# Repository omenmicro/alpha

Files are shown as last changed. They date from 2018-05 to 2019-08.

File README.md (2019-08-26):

# OMEN Alpha - [[česky](README-CZ.md)]

_8bit computer, based on 8085 CPU._



Become a Patron! (https://www.patreon.com/bePatron?u=23689010)

- [Essential ICs on AliExpress](https://alitronik.com/omen-alpha-pack/)
- [Essential ICs on eBay](https://alitronik.com/omen-alpha-pack-ebay/)

[BOM - Needed parts](./BOM.md)

I write a book about old computers. Oh, sorry: I mean "vintage computers" from the 80's. My primary goal is to show how one can build an 8bit computer from scratch.

It means: how to set up a CPU, how to connect memories, how to connect peripheral chips, and why to connect...

This computer is a "demo construction": A computer, based on 8085 CPU, with 32 kB of (EEP)ROM and 32 kB of RAM, serial connection and parallel ports. All should be as simple as possible. And here is a result.

ROM
---

Use the last Monitor file - see [sw/Monitor/v4](sw/Monitor/v4)

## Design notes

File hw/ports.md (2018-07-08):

JP2
+-----+-----+-----+-----+-----+
| GND | PA7 | PA6 | PA5 | PA4 |
+-----+-----+-----+-----+-----+
| Vcc | PA0 | PA1 | PA2 | PA3 |
+-----+-----+-----+-----+-----+

JP3
+-----+-----+-----+-----+-----+
| GND | PB7 | PB6 | PB5 | PB4 |
+-----+-----+-----+-----+-----+
| Vcc | PB0 | PB1 | PB2 | PB3 |
+-----+-----+-----+-----+-----+

JP4
+-----+-----+-----+-----+-----+
| GND | PC7 | PC6 | PC5 | PC4 |
+-----+-----+-----+-----+-----+
| Vcc | PC0 | PC1 | PC2 | PC3 |
+-----+-----+-----+-----+-----+

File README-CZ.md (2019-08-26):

# OMEN Alpha: Stavíme vlastní počítač  - [[English](README.md)]

_Samozřejmě osmibitový a s tak historickým duchem, jak to jen jde._



Become a Patron! (https://www.patreon.com/bePatron?u=23689010)

- [Essential ICs on AliExpress](https://alitronik.com/omen-alpha-pack/)
- [Essential ICs on eBay](https://alitronik.com/omen-alpha-pack-ebay/)

[BOM - Seznam součástek](./BOM.md)

Když jsem přemýšlel o tom, jak pojmout svou další knihy, bylo mi jasné, že suchý výklad nebude stačit. Tedy, on by stačil, ale já nejsem zrovna příznivcem teoretických učebnic bez přesahu do praxe. Bylo tedy samozřejmé, že nějakou konstrukci chci.

Ano, můžu vzít nějaký reálný osmibit a ukazovat na něm, jak se věci mají, možná vás i ponouknout ke stavbě repliky, ale touto cestou se mi moc jít nechtělo. Říkám si, že na vlastní konstrukci, která bude tak jednoduchá, jak jen to lze, půjde ilustrovat požadované věci mnohem líp.

Zvolil jsem tedy cestu konstrukce naprosto jednoduchých počítačů, které mají splňovat několik bodů:

1. Budou používat součástky, které se dají běžně koupit.
2. Nebudou se ortodoxně držet konstrukcí z 80. let - tedy když chci použít paměť, použiju moderní 128x8bit statickou RAM, což je jeden čip, a nebudu konstruovat zapojení z osmi čipů dynamické RAM a dalších tří IO kolem dokola.
3. Budou v duchu starých osmibitových časů, tedy jednoduché periferie - klávesnice, displej, reproduktor - a minimální softwarové vybavení.
4. Bude jednoduché psát pro ně software.
5. Klidně vynechám samotný starý procesor a potřebné funkce si naemuluju v moderním jednočipu. Nebo použiju jednočip místo periferií. No stress.

A maje tyto body na paměti jsem sednul a připravil několik konstrukcí, které jsou vhodné pro začátečníky - a tak vznikla "značka OMEN".

## OMEN?

Nojo. _Osmibitový Mikropočítač pro Elektronické Nadšence_. OMEN. A značení pomocí hláskového kódu: Alpha, Bravo, Charlie, Delta...

**OMEN Alpha** je jednoduchý počítač ve stylu jednodeskových strojů z konce 70. let s procesorem 8085. Obsahuje jen to nezbytné minimum, ovládáte jej pomocí terminálu, nebo pomocí připojené hexadecimální klávesnice a sedmisegmentového displeje.

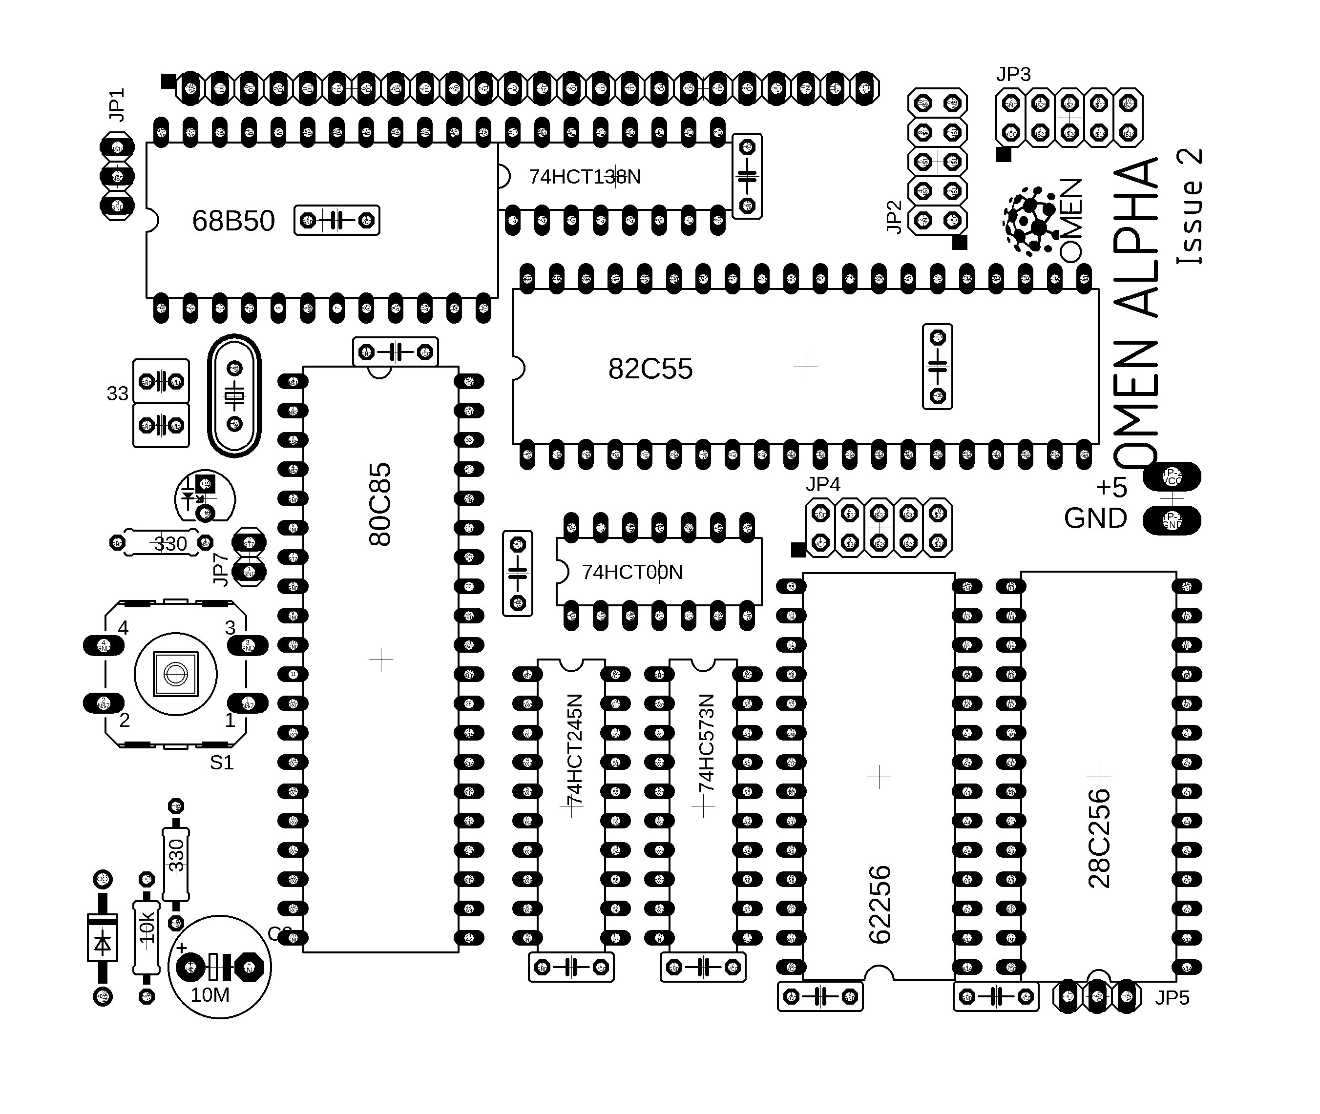
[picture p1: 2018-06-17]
hw/places.png

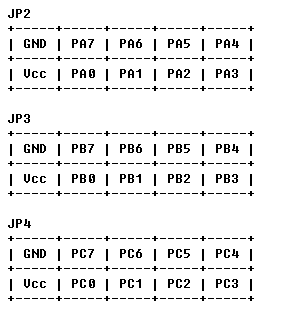
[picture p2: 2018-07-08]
hw/alpha-parallel.png

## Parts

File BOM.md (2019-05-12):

[OMEN Alpha](README.md) BOM:

- CPU 8085 (M5L8085A or equivalent type)
- RAM 32kx8 (62256 or equivalent)
- EEPROM 32kx8 (AT28C256 or equivalent)
- UART (MC68B50 or equivalent)
- PPI (8255A or equivalent)
- Decoder 74138 (HC or HCT)
- Driver 74245 (HC or HCT)
- Latch 74573 (HC or HCT)
- Gate 7400 (HC or HCT)
- A printed circuit board (with soldering mask)
- Crystal 3.6864 MHz
- Resonant capacitor 22 pF
- Push button
- Diode (1N4004 or similar)
- Resistors (1x 10k, 1x 330R)
- Electrolytic capacitor 10M
- Filter capacitor (8x 100n)

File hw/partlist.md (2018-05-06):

# Seznam součástek

| Part  | Value | Device |  Package | Library | Sheet |
|  :--- |  :--- |  :--- |  :--- |  :--- |  :--- |
| C1 |  6.8 | C-EU025-040X050 | C025-040X050 | rcl | 1 |
| C2 |  6.8 | C-EU025-040X050 | C025-040X050 | rcl | 1 |
| C3 |  10M | CPOL-EUE5-8.5 | E5-8,5 | rcl | 1 |
| C4 |  100n | C-EU050-025X075 | C050-025X075 | rcl | 1 |
| C5 |  100n | C-EU050-025X075 | C050-025X075 | rcl | 1 |
| C6 |  100n | C-EU050-025X075 | C050-025X075 | rcl | 1 |
| C7 |  100n | C-EU050-025X075 | C050-025X075 | rcl | 1 |
| C8 |  100n | C-EU050-025X075 | C050-025X075 | rcl | 1 |
| C9 |  100n | C-EU050-025X075 | C050-025X075 | rcl | 1 |
| C10 |  100n | C-EU050-025X075 | C050-025X075 | rcl | 1 |
| C11 |  100n | C-EU050-025X075 | C050-025X075 | rcl | 1 |
| C12 |  100n | C-EU050-025X075 | C050-025X075 | rcl | 1 |
| D1 |  1N4004 | 1N4004 | DO41-10 | diode | 1 |
| D2 |  G502DC | DIP-LED-GREEN-GREEN(D5MM)  | LED2-2.54-5.0MM| Seeed-LED | 1 |
| IC1 |  M5L8085AP  | 8085 | DIL40 | micro-intel | 1 |
| IC2 |  74HC573N | 74HC573N | DIL20 | 74xx-eu | 1 |
| IC3 |  62256 | 62256P | DIL28-6 | memory-hitachi  | 1 |
| IC4 |  28C256 | 28C256 | DIL28 | memory | 1 |
| IC5 |  74HCT00N | 74HCT00N | DIL14 | 74xx-eu | 1 |
| IC6 |  MC68B50 | 6850 | DIL24 | micro-motorola  | 1 |
| IC7 |  74HCT245N  | 74HCT245N | DIL20 | 74xx-eu | 1 |
| IC8 |  D82C55A | 8255A | DIL40 | micro-intel | 1 |
| IC9 |  74HCT138N  | 74HCT138N | DIL16 | 74xx-eu | 1 |
| JP1 | | PINHD-1X3 | 1X03 | pinhead | 1 |
| JP2 | | PINHD-2X5 | 2X05 | pinhead | 1 |
| JP3 | | PINHD-2X5 | 2X05 | pinhead | 1 |
| JP4 | | PINHD-2X5 | 2X05 | pinhead | 1 |
| Q1 |  3.6864 | CRYSTALHC49S | HC49/S | crystal | 1 |
| R1 |  10k | R-EU_0207/10 | 0207/10 | rcl | 1 |
| R2 |  330 | R-EU_0207/10 | 0207/10 | rcl | 1 |
| R3 |  330 | R-EU_0207/7 | 0207/7 | rcl | 1 |
| S1 |  Pushbutton | 40-XX | B3F-40XX | adafruit | 1 |
| TP1 |  TP2P2-38-17| TP2P2-38-17 | P2-38-17 | testpad | 1 |

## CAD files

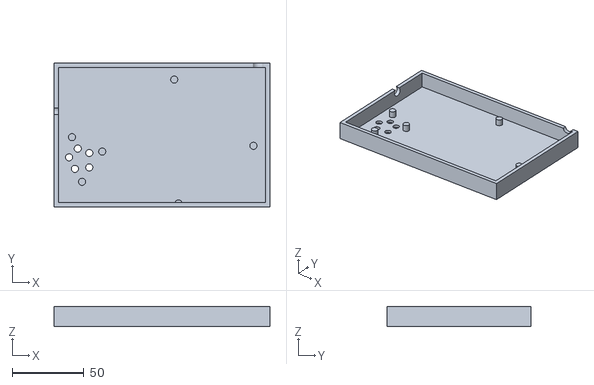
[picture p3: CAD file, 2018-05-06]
hw/Case/Omen Alpha.stl
150.0 x 100.0 x 14.0

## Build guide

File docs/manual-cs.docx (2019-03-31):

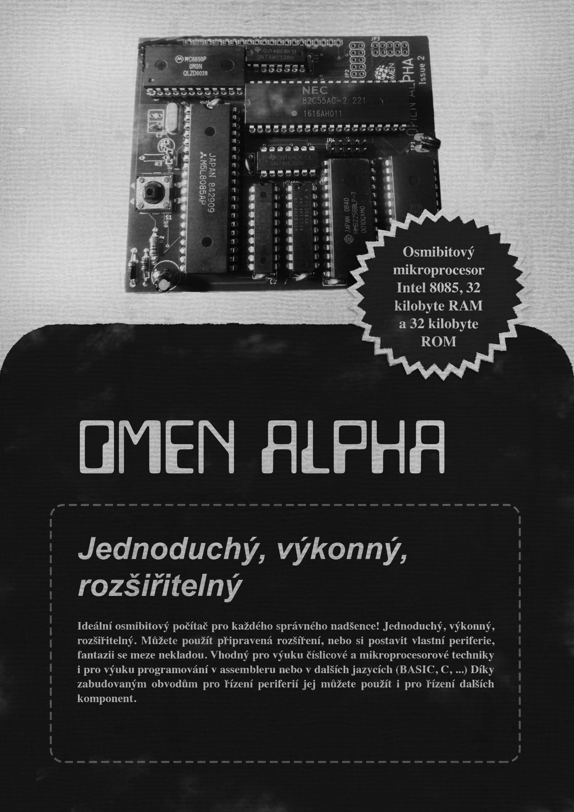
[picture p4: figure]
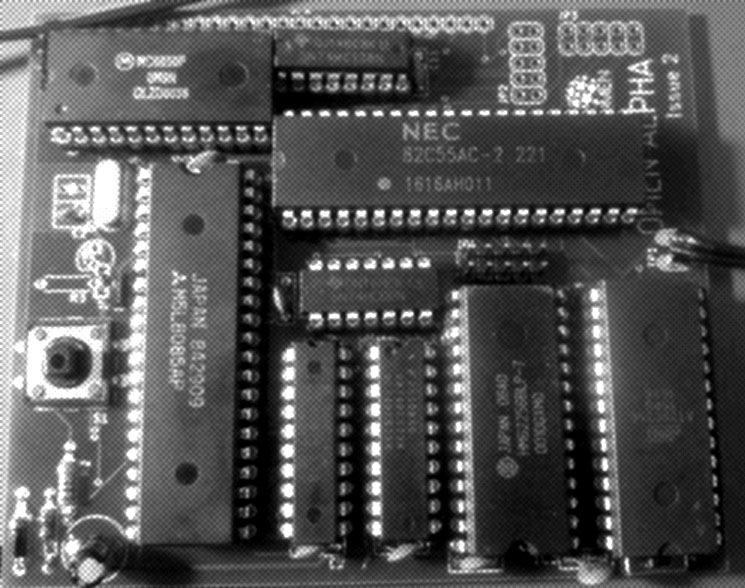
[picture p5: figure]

OMEN Alpha / issue 4

Technická dokumentace

ÚVOD
====

OMEN Alpha /Osmibitový Mikropočítač pro Elektronické Nadšence/ je jednoduchý jednodeskový počítač, postavený na procesoru Intel 8085. Jeho základní parametry jsou:

- 8085 / 80C85 CPU na frekvenci 1.8432 MHz
- 32 kB RAM
- 32 kB EEPROM
- Sériový komunikační port s rychlostí až 115.200 Bd / MC6850
- 3 paralelní porty / Intel 8255
- Aplikační sběrnice

NÁVOD K SESTAVENÍ

===============

1. Zapájejte patice pro integrované obvody
2. Zkontrolujte, zda spojení fungují
  a. Otestujte, zda všechny piny jsou propojené jak mají
  b. Proměřte, zda není zkrat mezi napájením a zemí
  c. Zkontrolujte, jestli všechny integrované obvody mají přivedené napájení
3. Připájejte pasivní součástky /kondenzátory, diodu, tlačítko, krystal, rezistory/
4. Připojte napájecí napětí a zkontrolujte, zda vše funguje
5. Vložte procesor do patice /pozor na správnou orientaci!/ a zkuste zapnout napájecí napětí. Zkontrolujte, zda oscilátor funguje / CPU vývod 37/ - Rychlý tip: voltmetr by měl ukázat napětí 2-3V
6. Vložte do patic všechny ostatní integrované obvody. Opět: dbejte na správnou orientaci! Otočení obvodu může vést k jeho zničení.
7. Propojku JP5 nastavte na piny 1-2!
8. Připojte sériové signály TxD, RxD a GND /pinhead JP1/ k převodníku na USB. Nezapomeňte, že TxD na desce musí být připojeno k RxD na převodníku a obráceně!
9. Spusťte terminálový program na PC, vyberte správný port a parametry nastavte na 115.200 Bd, 8 data bits, no parity, 1 stop bit.
10. Zapněte napájení a sledujte terminál. Měl by se ohlásit Monitor

MONITOR

=======

Základní programové vybavení OMEN Alpha tvoří monitor MON85 od Dave Dunfielda, ve verzi upravené Romanem Bórikem.

Manuál najdete na https://8bt.cz/mon85 nebov Příloze 1

Můžete spustit zabudovaný TINY Basic příkazem “G1000” /bez uvozovek/ a stiskem ENTER. Z BASICu se zpět do Monitoru dostanete příkazem BYE.

DESKA PLOŠNÝCH SPOJŮ

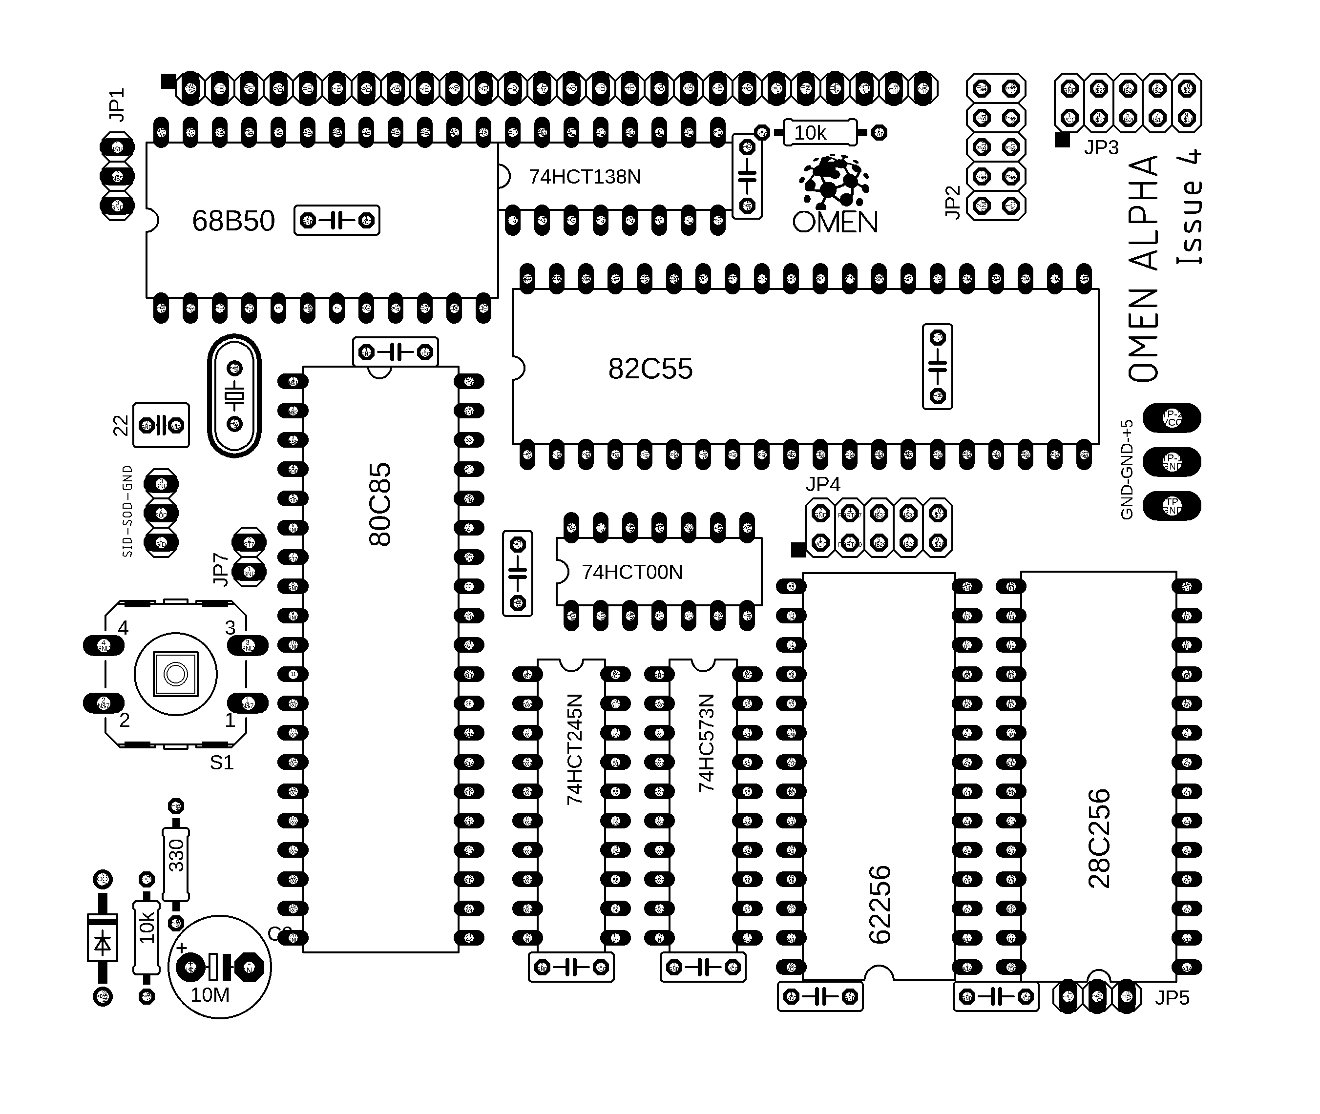
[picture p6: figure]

==================

Vývody, piny a přepínače

JP1: Sériový port. Vývody jsou GND, TxD, RxD zleva doprava, RxD je vedle nápisu JP1

JP2, JP3, JP4: Paralelní porty, viz níže. Značka označuje pin 1 - Vcc

JP5: Povolení zápisu do EEPROM. Spojení pinů 1 a 2 zakazuje zápis, spojení 2 a 3 jej povoluje. Normálně jsou propojeny 1 a 2. Pin 1 je vlevo, pin 3 vedle nápisu! Pokud nepočítáte s budoucím zápisem, zapájejte propojky 1-2 napevno!

JP7: Povolení vstupu RST7.5. Nechte propojené, případně zapojte rezistor 10 k

JP8: Sériové signály SID a SOD

PARALELNÍ PORTY

=============

JP2:

+-----+-----+-----+-----+-----+
| GND | PA7 | PA6 | PA5 | PA4 |
+-----+-----+-----+-----+-----+
| Vcc | PA0 | PA1 | PA2 | PA3 |
+-----+-----+-----+-----+-----+

JP3:

+-----+-----+-----+-----+-----+
| GND | PB7 | PB6 | PB5 | PB4 |
+-----+-----+-----+-----+-----+
| Vcc | PB0 | PB1 | PB2 | PB3 |
+-----+-----+-----+-----+-----+

JP4:

+-----+-----+-----+-----+-----+
| GND | PC7 | PC6 | PC5 | PC4 |
+-----+-----+-----+-----+-----+
| Vcc | PC0 | PC1 | PC2 | PC3 |
+-----+-----+-----+-----+-----+

APLIKAČNÍ KONEKTOR

=========================

Konektor je na horním okraji desky, pin 1 je označen značkou a je vlevo

Pins:

1 /WR
2 D0
3 D1
4 D2
5 D3
6 D4
7 D5
8 D6
9 D7
10 A0
11 A1
12 A2
13 /RD
14 IO1 --- 20h – 27h
15 IO2 --- 10h – 17h
16 IO3 --- 30h – 37h
17 IO4 --- 08h – 0Fh IOx signály jsou dekódovány z adresy
18 IO5 --- 28h – 2Fh
19 IO6 --- 18h – 1Fh
20 IO7 --- 38h – 3Fh
21 Vcc
22 GND
23 RST7.5 -- viz JP7
24 CLK
25 RESET -- výstup
26 READY -- Úroveň 0 vyvolá WAIT stav
27 /BUSRQ /není použito v této verzi/
28 /BUSACK /není použito v této verzi /
29 /není použito v této verzi /
30 /není použito v této verzi /

ADRESY PERIFERIÍ
==============

ACIA 6850 – sériový port:
--------------------

DEh – Controll Register / Status Register

DFh – Data Register

PPI 8255 – paralelní port:
---------------------

04h – PORT A

05h – PORT B

06h – PORT C

07h – Control port

MAPA PAMĚTI
==========

0000h – 7FFFh - EEPROM 32k

8000h – FFFFh – System RAM

PŘÍLOHA 1 – Monitor MON85

=========================

MON85

A

Software Debug Monitor

For the 8085/8080

Dunfield Development Systems

High quality tools for

Embedded Development

at low prices.

http://www.dunfield.com

Copyright 1979-2007 Dave Dunfield

All rights reserved

MON85

OBSAH

1. ÚVOD

1.1 8085 Restart Interrupts

1.2 Breakpoints

2. PŘÍKAZY MON85

2.1 A ON|OFF

2.2 B [0-7 address]

2.3 C <source> <destination> <size>

2.4 D <address>

2.5 E <address>

2.6 F <start> <end> <value>

2.7 G [address]

2.8 I <port>

2.9 L [address]

2.10 M <address>

2.11 O <port> <data>

2.12 R [rp value]

2.13 S ON|OFF

2.14 T ON|OFF

2.15 U [address]

2.16 ?

3. SEZNAM PŘÍKAZŮ

1. ÚVOD

MON85 is a ROMable interactive debugging program for the 8085

processor, which contains a full complement of commands to monitor

and control the execution of your program. It may also be used on an

8080 processor, as long as you do not attempt to use the 8085

specific SIM and RIM instructions, or the '.5' type interrupt

vectors.

MON85 must be installed beginning at location $0000 in the 8085

processor memory map, allowing it to intercept the interrupt vectors.

Provision has been made to re-vector interrupts to locations within

the user program.

All functions of MON85 are performed via software without hardware

assist. The only hardware specific subroutines required by the

monitor are used to communicate with the console terminal, and are

located at the very end of the monitor source code listing:

INIT - Called to initialize any hardware required for I/O.

OUT - Write the character in A to the console. No processor

registers should be modified by this routine.

IN - Test for a character from the console, and return it

in A if one is available. Otherwise clear A to zero.

No other registers should be modified by this routine.

1.1 8085 Restart Interrupts

MON85 reserves two "restart" interrupts: RST 0 is similar to a

physical RESET, causes a cold restart of the monitor. This

instruction should be used with CAUTION during a debugging session

because any breakpoints set in the user program will be

"forgotten", and not properly removed. RST 1 is used by MON85 to

regain control at breakpoints. Opcodes of breakpointed

instructions are replaced by RST 1 whenever the user program is

executed, and are restored whenever the monitor is re-entered.

This insures that the operation of breakpoints is transparent to

you during the debugging session.

If for any reason a 'RST 1' ($CF) instruction is encountered in

the user program (and is not a breakpoint), command mode will be

entered without the '** Breakpoint' message.

All other "restart" interrupts are re-vectored to the

corresponding locations in the first page of memory occupied by

the user program (as identified by the 'U' command).

1.2 Breakpoints

MON85 allows you to set breakpoints in your program, such that

you will be given control whenever the program reaches a

breakpoint, and can examine or change things before proceeding.

MON85 also allows you to TRACE a program, so that you can see each

instruction and register contents as it executes.

MON85 is completely transparent to the program being tested

(unless timing loops are interrupted with BREAKPOINTS or TRACE).

When a breakpoint is encountered, or an instruction is traced,

MON85 uses one stack entry on the user program stack. Since this

consists of a PUSH and a POP, it should not affect any information

stacked by the user program. However, you should be aware of this,

in case you are examining the stack, or your program trys to

reclaim data already popped from the stack. (It is very poor

practice, to write programs which depend on the stack contents

below the stack pointer).

When a breakpoint is encountered, the message '** Breakpoint n'

is printed where n is the number of the breakpoint (0-7). If TRACE

is ON, no other action is taken, otherwise command mode is entered

(If the 'A' switch (see below) is ON the registers are also

displayed).

2. MON85 COMMANDS

The following commands are recognized by MON85, and may be entered

whenever MON85 is in COMMAND MODE, which is indicated by the 'C> '

prompt:

2.1 A ON|OFF

This switch turns ON or OFF the automatic register display which

occurs whenever a breakpoint is encountered or an instruction is

stepped in trace mode (see below). The default value for 'A' is

ON.

2.2 B [0-7 address]

Sets one of eight breakpoints [0-7] at the specified address. Once

set, a breakpoint remains in effect until it is removed by setting

it to address ZERO (0). Breakpoints are completely invisible, and

may be added, removed or changed at any time without adverse

affects. If the 'B' command is issued with no operands, the

current breakpoints, and the settings of the 'A', 'S' and 'T'

flags (see below) are displayed. A displayed address of '****'

indicates that a breakpoint is not set.

2.3 C <zdroj> <cíl> <počet>

Kopíruje <počet> bytů paměti z místa daného adresou <zdroj> do oblasti
od adresy <cíl>.

2.4 D <adresa>

Displays memory in assembly listing format, starting at <address>,

continuing until an ESCAPE character is entered. Output can be

temporarily stopped with the SPACE BAR, and restarted with the

RETURN key (Additional SPACE's will output single lines). The

output is displayed in the following form:

'<address> <opcodes> <ascii> <instruction>'

<address> is the current memory location, <opcodes> is the

instruction opcodes (1, 2 or 3 bytes), <ascii> is ASCII

representation of <opcodes> (all non-printable characters are

displayed as dots), and <instruction> is the assembly language

instruction and operands which <opcodes> represents.

2.5 E <address>

Edits memory, starting at <address>. The address, and its contents

are displayed, followed by a '=' prompt. Sub commands are:

nn [nn ...] - Replace memory contents with HEX data bytes

'text ... - Replace memory contents with ASCII text

- - Backup to previous locations

<blank line>- Advance to next location with change

<ESCAPE> - Return to MON85 command prompt

2.6 F <start> <end> <value>

Fills memory between the <start> and <end> addressses with the

specified <value>.

2.7 G [address]

Loads the user program registers, and begins execution at the

specified address. If no [address] is given, execution begins at

the address contained in the user program program counter (PC). A

simple 'G' with no operands, is all that is needed to resume

execution after a breakpoint interrupt, or to resume trace mode

exection.

2.8 I <port>

Reads the specified 8085 I/O port, and displays the data.

2.9 L [address]

Downloads code from the console port. MON85 will recognize and

accept either INTEL or MOTOROLA hex format download records. The

address in the FIRST download record is recorded as the program

BASE address (See 'U' command). If an [address] is given, the

address fields of each record are adjusted so that the code image

will be loaded into memory beginning at that address, otherwise it

is placed in memory at the absolute address contained in each

record.

If you accidently enter this command, you may enter either 'S9' or

':00' to signify a null download file and return to the command

prompt.

2.10 M <address>

Displays memory in HEX/ASCII dump format starting at the specified

address. ESCAPE, SPACE, and CARRIAGE-RETURN can be used to control

the listing, the same is with the 'D' command.

2.11 O <port> <data>

This command writes the <data> byte to the specified 8085 I/O

<port>.

2.12 R [rp value]

Changes the contents of the user program register pair <rp> to the

specified <value>. Valid pairs are BC, DE, HL, SP, PC, and PSW. If

no operands are given, the contents of the user program registers

are displayed.

2.13 S ON|OFF

Controls the handling of subroutine calls when in trace mode (see

below). When 'S' is set ON, subroutines will be be traced in the

normal fashion. When set OFF, subroutines calls are not traced,

and trace will resume at the next instruction following the CALL

(After the subroutine executes).

WARNING: DO NOT SET BREAKPOINTS IN THE SUBROUTINES WHEN 'S' IS SET

OFF. When 'S' is set off, MON85 considers the subroutine (and all

of it's embedded instructions) to be one single operation. If a

breakpoint is encountered inside the subroutine, TRACE will lose

the address at which to resume following the subroutine call. This

will cause unpredictable action when the subroutine returns.

Otherwise, 'S' may be turned on and off at any time with no

adverse effects. The default value for 'S' is ON.

2.14 T ON|OFF

Turns TRACE mode ON and OFF. When TRACE is set ON, and the GO

command is issued, MON85 will first prompt with 'T>' before

beginning program execution.

Entering a space (' ') will display and execute one instruction,

and return to the 'T>' prompt.

Entering '?' will display the processor registers. (If the 'A'

switch is set ON, they will always be displayed following every

instruction that is traced).

An ESCAPE charecter will cause MON85 to return to the usual

command prompt (TRACE remains ON, and will resume with the next

'G' command).

Trace may be turned on and off at any time in a program, with no

adverse effects. (If you begin execution with TRACE off, you will

have to hit a breakpoint to get you back to command mode before

you can turn TRACE on).

When a breakpointed instruction is encountered by the tracer, The

message '** Breakpoint n' will be issued at the end of the

previous instruction, indicating that the breakpointed instruction

occurs NEXT. Pressing the SPACE BAR would then execute the

breakpointed instruction. The default value for 'T' is OFF.

2.15 U [address]

Identifies the starting address of a user program. MON85 uses this

address to re-map the "restart" interrupt vectors. When a 'L'oad

command is performed, MON85 initializes 'U' to the address

contained in the first download record. If no [address] is

specified, MON85 will display the current user program starting

address.

2.16 ?

This command displays a short summary of the other MON85 commands.

3. COMMAND SUMMARY

A ON/OFF - Enables/Disables auto register display.

B [0-7 address] - Sets/Removes/Displays breakpoints.

C <src> <dest> <size> - Copy memory

D <address> - Displays memory in disassembly format.

E <address> - Edit memory contents.

F <start> <end> <value> - Fill memory with a value.

G [address] - Begin/Resume program execution.

I <port> - Input from port

L [address] - Download from host

M <address> - Displays memory in dump format.

O <port> <data> - Output to port

R [rp value] - Sets/Displays register contents.

S ON|OFF - Enables/Disables subroutine traceing.

T ON|OFF - Enables/Disables TRACE mode.

U [address] - Set/Displays program base address.

? - Display command summary

MON85 Improvements by Martin Borik:

- Support for undocumented 8085 instructions DSUB B, ARHL, RDEL, LDHI d8, LDSI d8, LHLX D, SHLX D, JNK a16, JK a16, RSTV
- Command R displays all flags of F register (SZKA3PVC). If flag is not set dash '-' is displayed.
- Added restart vector RST 8 (0040h) for possibility to handle RSTV call.
- Changed TRACE mode. After entering TRACE mode, instruction on actual PC and content of registers (if it is switched on) are displayed. Entering a space ' ' executes this instruction, and returns to the 'T>' prompt with the next instruction.
- Instructions LXI, DAD, INX, DCX displays argument 'SP' rather than 'S'.
- Commands that requires 1 byte parameter raises error if entered value not fit to 1 byte.
- Command 'C' checks overlap of source and destination block and for copying uses appropriate direction.
- Command 'F' checks <start> and <end> parameters and raises error, if <end> is lower than <start>.
- Added command 'H' to send out memory content in Intel HEX format.
- Sending of LF and CR characters were reversed and are sent in the usual order - CR first and followed by LF.

OMEN Computers - - - https://github.com/osmibity - - - Strana: 1

OMEN ALPHA =========

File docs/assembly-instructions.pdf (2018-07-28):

# OMEN Alpha

1. You will need:

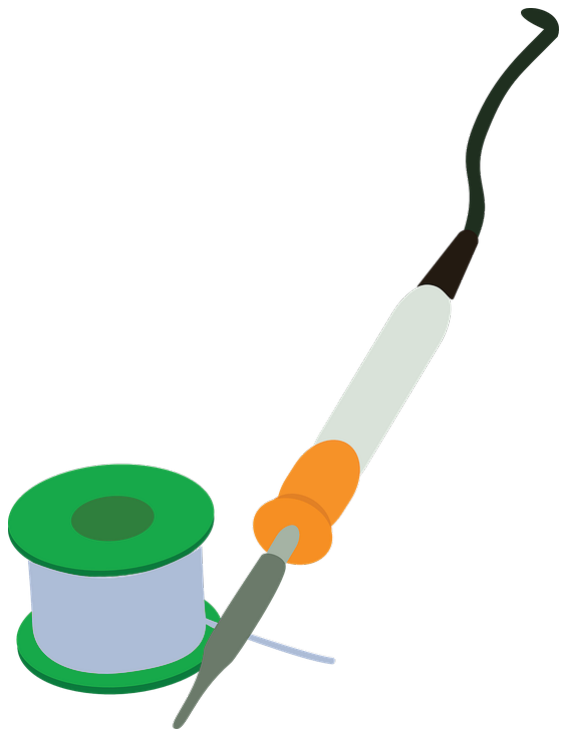
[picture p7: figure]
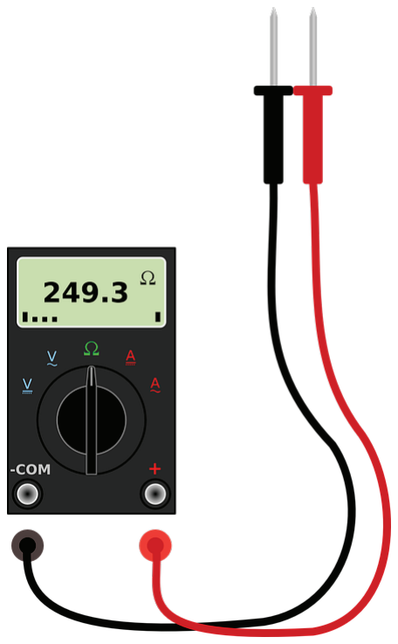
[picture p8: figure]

2. Solder sockets for integrated circuits. Sockets and pinheaders are not included in the kit!
4. Solder all pasive parts (capacitors, diode, resistors, pushbutton, crystal)
5. Connect the power (+5 V) and check.
10. Power the Alpha and check the terminal.
7. Insert the essential ICs: 74245, 74573, 7400,

RAM 62256 and EEPROM 28C256 (programmed)

9. Connect the serial USB to your PC and set it (115200 Bd, 8 data bits, no parity, 1 stop bit. Use Teraterm, Putty, or other serial terminal)
6. Insert the CPU into the socket and try to

power it up. Check the oscillator (CPU pin 37).

8. Connect the UART 68B50 and the TTL-USB

interface (three wires: TxD, RxD and GND)

3. Test all soldered connections:

Test if all pins are well connected.
Check if GND is not short connected to Vcc
Check if every IC has properly connected GND and Vcc

Assembly instructions

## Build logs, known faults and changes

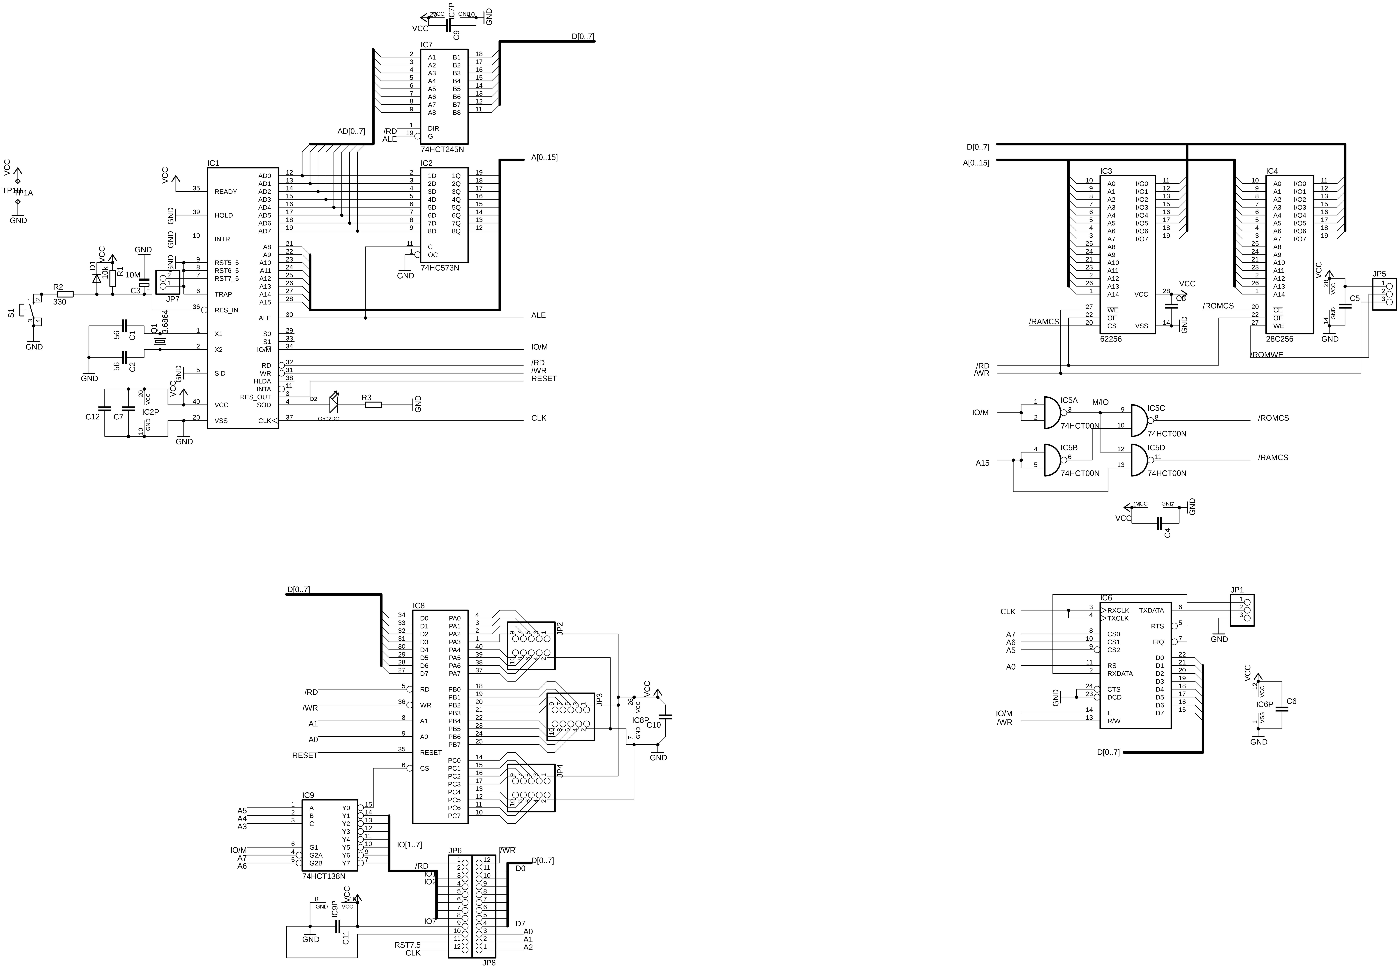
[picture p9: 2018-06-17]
hw/schematics-issue2.png

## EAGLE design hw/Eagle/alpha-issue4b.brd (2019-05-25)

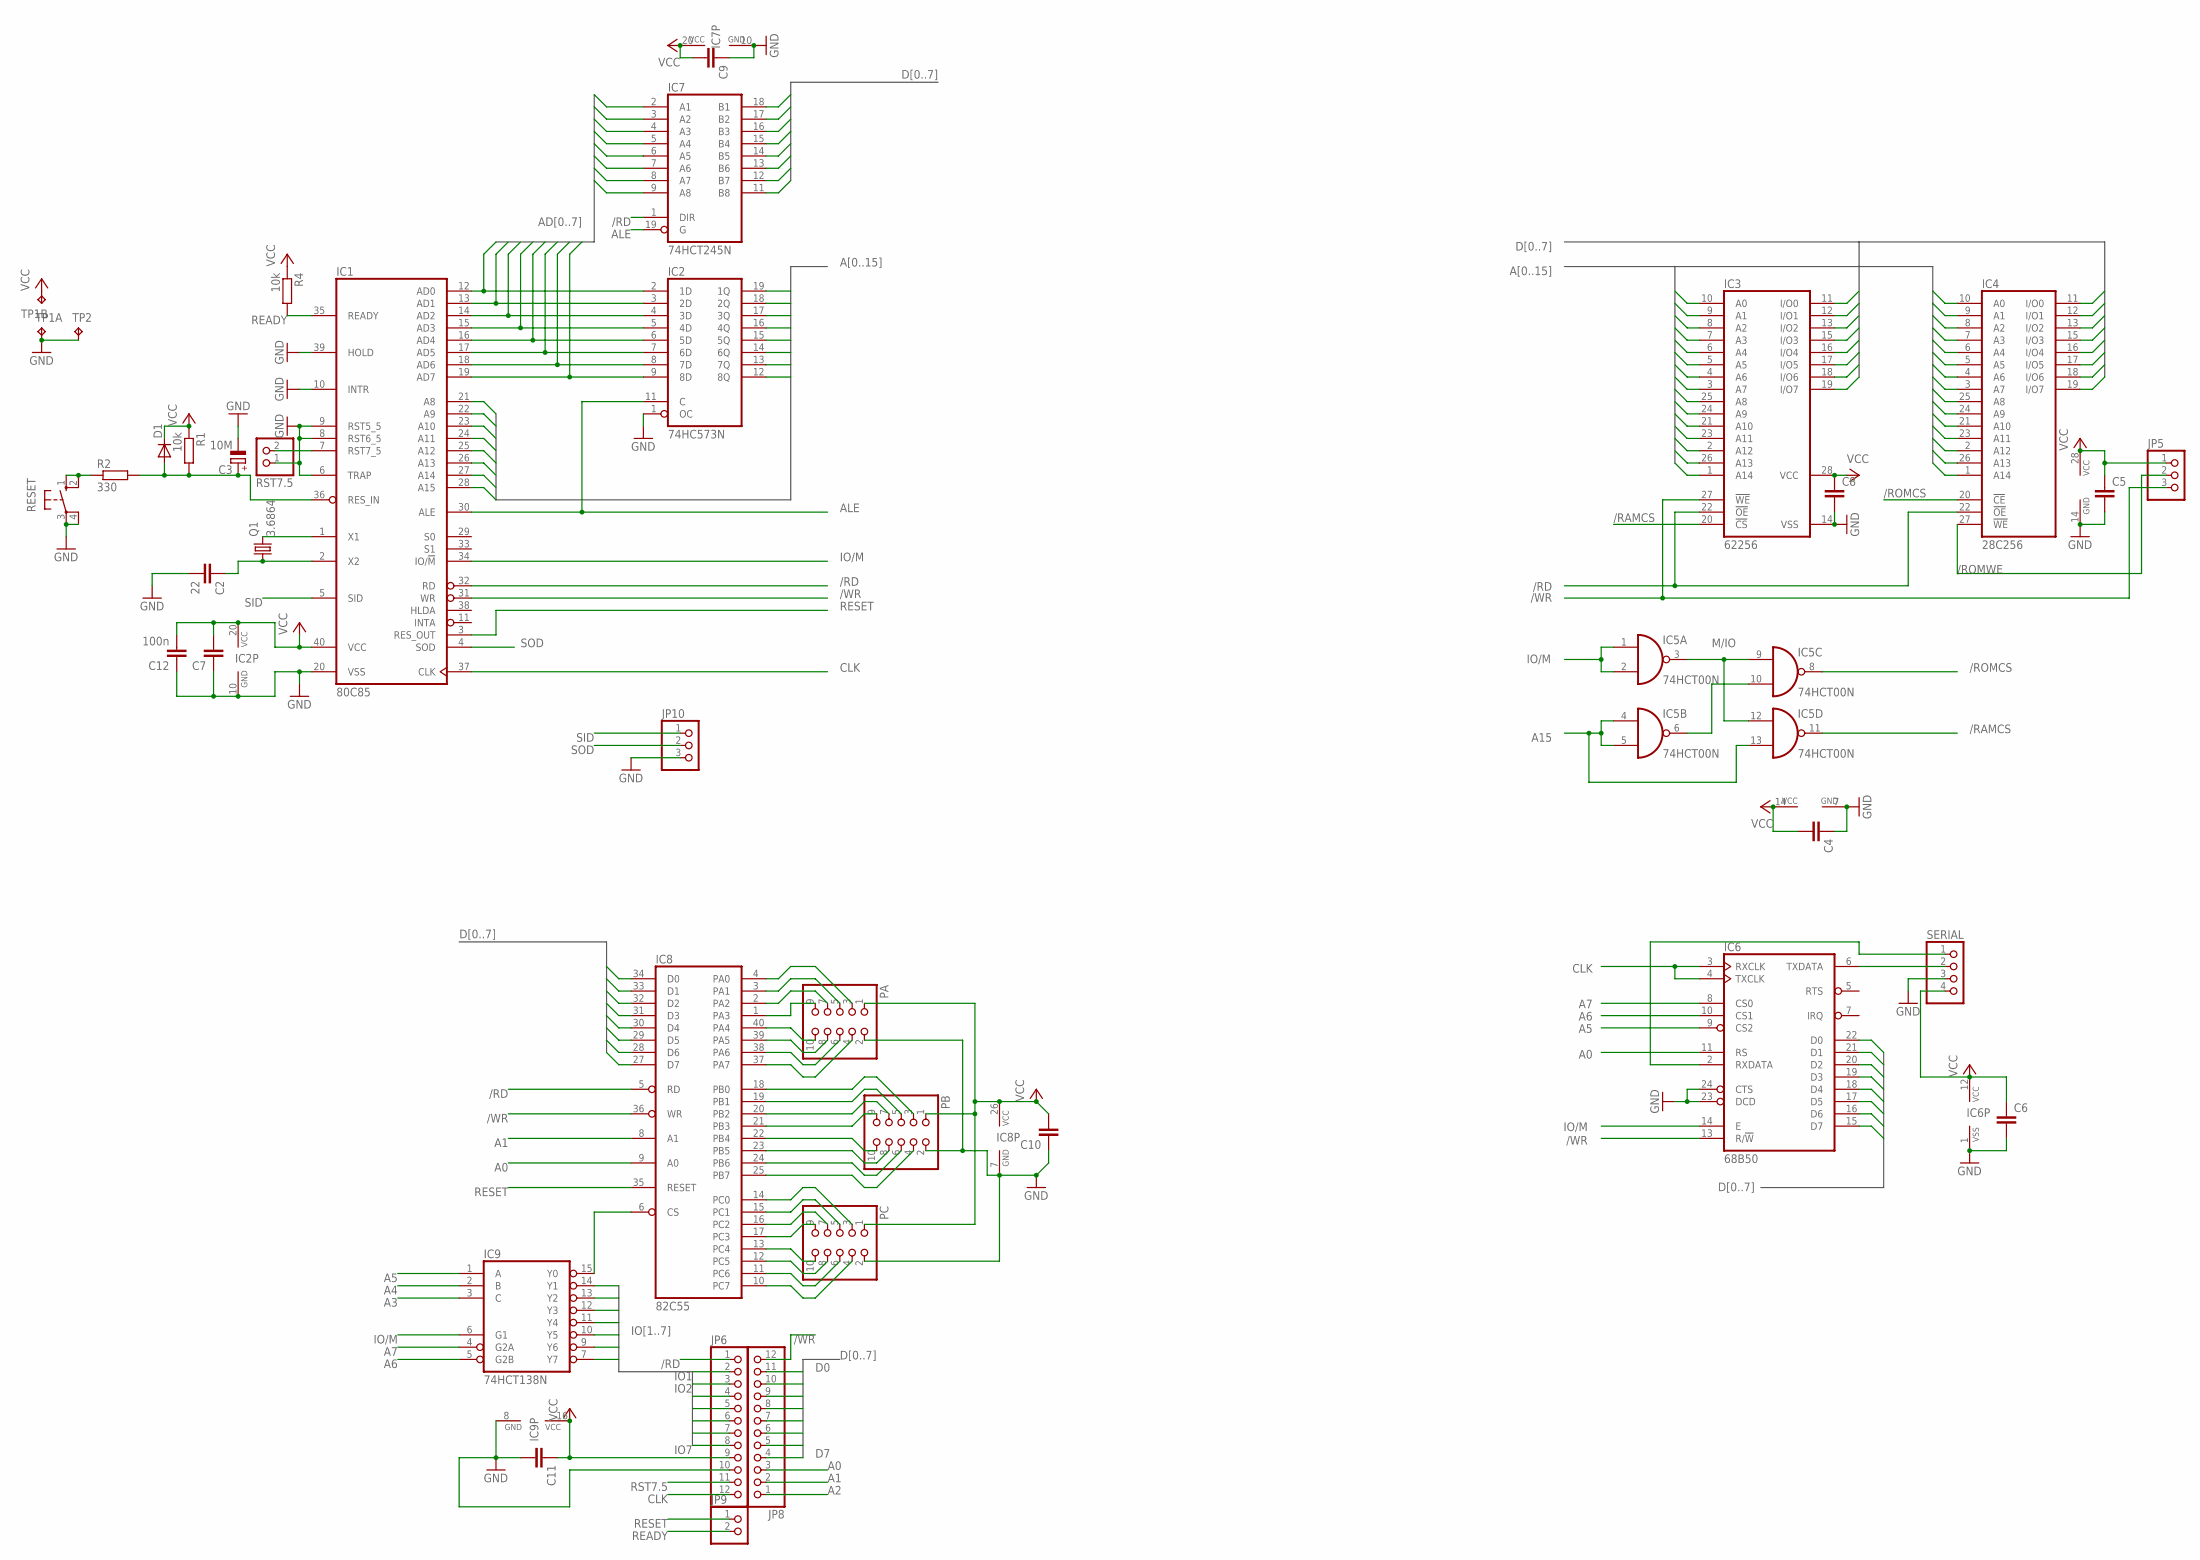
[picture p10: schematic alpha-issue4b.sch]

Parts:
C2: 22; C025-040X050
C3: 10M; E5-8,5
C4, C5, C6, C7, C8, C9, C10, C11: C-EU050-025X075; C050-025X075
C12: 100n; C050-025X075
D1: 1N4004; DO41-10
IC1: 80C85; DIL40
IC2: 74HC573N; DIL20
IC3: 62256; DIL28-6
IC4: 28C256; DIL28
IC5: 74HCT00N; DIL14
IC6: 68B50; DIL24
IC7: 74HCT245N; DIL20
IC8: 82C55; DIL40
IC9: 74HCT138N; DIL16
JP5, JP10: PINHD-1X3; 1X03
JP6, JP8: PINHD-1X12; 1X12
JP9: PINHD-1X2; 1X02
PA: PINHD-2X5; 2X05
PB: PINHD-2X5; 2X05
PC: PINHD-2X5; 2X05
Q1: 3.6864; HC49/S
R1: 10k; 0207/10
R2: 330; 0207/10
R4: 10k; 0204/7
RESET: 40-XX; B3F-40XX
RST7.5: PINHD-1X2; 1X02
SERIAL: PINHD-1X4; 1X04
TP1: TP2P2-38-17; P2-38-17
TP2: TPPAD1-17Y; P1-17Y

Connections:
/RAMCS: IC3.20 (!CS), IC5.11 (O)
/RD: IC1.32 (RD), IC3.22 (!OE), IC4.22 (!OE), IC7.1 (DIR), IC8.5 (RD), JP6.1
/ROMCS: IC4.20 (!CE), IC5.8 (O)
/ROMWE: IC4.27 (!WE), JP5.2
/WR: IC1.31 (WR), IC3.27 (!WE), IC6.13 (R/!W), IC8.36 (WR), JP5.3, JP8.12
A0: IC2.19 (1Q), IC3.10 (A0), IC4.10 (A0), IC6.11 (RS), IC8.9 (A0), JP8.3
A1: IC2.18 (2Q), IC3.9 (A1), IC4.9 (A1), IC8.8 (A1), JP8.2
A2: IC2.17 (3Q), IC3.8 (A2), IC4.8 (A2), JP8.1
A3: IC2.16 (4Q), IC3.7 (A3), IC4.7 (A3), IC9.3 (C)
A4: IC2.15 (5Q), IC3.6 (A4), IC4.6 (A4), IC9.2 (B)
A5: IC2.14 (6Q), IC3.5 (A5), IC4.5 (A5), IC6.9 (CS2), IC9.1 (A)
A6: IC2.13 (7Q), IC3.4 (A6), IC4.4 (A6), IC6.10 (CS1), IC9.5 (G2B)
A7: IC2.12 (8Q), IC3.3 (A7), IC4.3 (A7), IC6.8 (CS0), IC9.4 (G2A)
A8: IC1.21 (A8), IC3.25 (A8), IC4.25 (A8)
A9: IC1.22 (A9), IC3.24 (A9), IC4.24 (A9)
A10: IC1.23 (A10), IC3.21 (A10), IC4.21 (A10)
A11: IC1.24 (A11), IC3.23 (A11), IC4.23 (A11)
A12: IC1.25 (A12), IC3.2 (A12), IC4.2 (A12)
A13: IC1.26 (A13), IC3.26 (A13), IC4.26 (A13)
A14: IC1.27 (A14), IC3.1 (A14), IC4.1 (A14)
A15: IC1.28 (A15), IC5.4 (I0), IC5.5 (I1), IC5.13 (I1)
ALE: IC1.30 (ALE), IC2.11 (C), IC7.19 (G)
CLK: IC1.37 (CLK), IC6.3 (RXCLK), IC6.4 (TXCLK), JP6.12
D0: IC3.11 (I/O0), IC4.11 (I/O0), IC6.22 (D0), IC7.18 (B1), IC8.34 (D0), JP8.11
D1: IC3.12 (I/O1), IC4.12 (I/O1), IC6.21 (D1), IC7.17 (B2), IC8.33 (D1), JP8.10
D2: IC3.13 (I/O2), IC4.13 (I/O2), IC6.20 (D2), IC7.16 (B3), IC8.32 (D2), JP8.9
D3: IC3.15 (I/O3), IC4.15 (I/O3), IC6.19 (D3), IC7.15 (B4), IC8.31 (D3), JP8.8
D4: IC3.16 (I/O4), IC4.16 (I/O4), IC6.18 (D4), IC7.14 (B5), IC8.30 (D4), JP8.7
D5: IC3.17 (I/O5), IC4.17 (I/O5), IC6.17 (D5), IC7.13 (B6), IC8.29 (D5), JP8.6
D6: IC3.18 (I/O6), IC4.18 (I/O6), IC6.16 (D6), IC7.12 (B7), IC8.28 (D6), JP8.5
D7: IC3.19 (I/O7), IC4.19 (I/O7), IC6.15 (D7), IC7.11 (B8), IC8.27 (D7), JP8.4
DX0: IC1.12 (AD0), IC2.2 (1D), IC7.2 (A1)
DX1: IC1.13 (AD1), IC2.3 (2D), IC7.3 (A2)
DX2: IC1.14 (AD2), IC2.4 (3D), IC7.4 (A3)
DX3: IC1.15 (AD3), IC2.5 (4D), IC7.5 (A4)
DX4: IC1.16 (AD4), IC2.6 (5D), IC7.6 (A5)
DX5: IC1.17 (AD5), IC2.7 (6D), IC7.7 (A6)
DX6: IC1.18 (AD6), IC2.8 (7D), IC7.8 (A7)
DX7: IC1.19 (AD7), IC2.9 (8D), IC7.9 (A8)
GND: C2.2, C3.-, C4.1, C5.2, C6.2, C7.1, C8.2, C9.1, C10.1, C11.2, C12.1, IC1.6 (TRAP), IC1.8 (RST6_5), IC1.9 (RST5_5), IC1.10 (INTR), IC1.20 (VSS), IC1.39 (HOLD), IC2.1 (OC), IC2.10 (GND), IC3.14 (VSS), IC4.14 (GND), IC5.7 (GND), IC6.1 (VSS), IC6.23 (DCD), IC6.24 (CTS), IC7.10 (GND), IC8.7 (GND), IC9.8 (GND), JP6.10, JP10.3, PA.2, PB.2, PC.2, RESET.3, RESET.4 (P1), RST7.5.1, SERIAL.3, TP1.TP-1, TP2.TP
IO1: IC9.14 (Y1), JP6.2
IO2: IC9.13 (Y2), JP6.3
IO3: IC9.12 (Y3), JP6.4
IO4: IC9.11 (Y4), JP6.5
IO5: IC9.10 (Y5), JP6.6
IO6: IC9.9 (Y6), JP6.7
IO7: IC9.7 (Y7), JP6.8
IO/M: IC1.34 (IO/!M), IC5.1 (I0), IC5.2 (I1), IC6.14 (E), IC9.6 (G1)
M/IO: IC5.3 (O), IC5.9 (I0), IC5.12 (I0)
unnamed: IC1.1 (X1), Q1.2
unnamed: C2.1, IC1.2 (X2), Q1.1
unnamed: IC6.6 (TXDATA), SERIAL.2
unnamed: C3.+, D1.A, IC1.36 (RES_IN), R1.2, R2.2
unnamed: R2.1, RESET.1 (S), RESET.2 (S1)
unnamed: IC5.6 (O), IC5.10 (I1)
unnamed: IC8.1 (PA3), PA.9
unnamed: IC6.2 (RXDATA), SERIAL.1
unnamed: IC8.2 (PA2), PA.7
unnamed: IC8.3 (PA1), PA.5
unnamed: IC8.4 (PA0), PA.3
unnamed: IC8.40 (PA4), PA.10
unnamed: IC8.39 (PA5), PA.8
unnamed: IC8.38 (PA6), PA.6
unnamed: IC8.37 (PA7), PA.4
unnamed: IC8.21 (PB3), PB.9
unnamed: IC8.20 (PB2), PB.7
unnamed: IC8.19 (PB1), PB.5
unnamed: IC8.18 (PB0), PB.3
unnamed: IC8.22 (PB4), PB.10
unnamed: IC8.23 (PB5), PB.8
unnamed: IC8.24 (PB6), PB.6
unnamed: IC8.25 (PB7), PB.4
unnamed: IC8.17 (PC3), PC.9
unnamed: IC8.13 (PC4), PC.10
unnamed: IC8.16 (PC2), PC.7
unnamed: IC8.15 (PC1), PC.5
unnamed: IC8.12 (PC5), PC.8
unnamed: IC8.11 (PC6), PC.6
unnamed: IC8.6 (CS), IC9.15 (Y0)
PORTC0: IC8.14 (PC0), PC.3
PORTC7: IC8.10 (PC7), PC.4
READY: IC1.35 (READY), JP9.2, R4.2
RESET: IC1.3 (RES_OUT), IC8.35 (RESET), JP9.1
RST7.5: IC1.7 (RST7_5), JP6.11, RST7.5.2
SID: IC1.5 (SID), JP10.1
SOD: IC1.4 (SOD), JP10.2
VCC: C4.2, C5.1, C6.1, C7.2, C8.1, C9.2, C10.2, C11.1, C12.2, D1.C, IC1.40 (VCC), IC2.20 (VCC), IC3.28 (VCC), IC4.28 (VCC), IC5.14 (VCC), IC6.12 (VCC), IC7.20 (VCC), IC8.26 (VCC), IC9.16 (VCC), JP5.1, JP6.9, PA.1, PB.1, PC.1, R1.1, R4.1, SERIAL.4, TP1.TP-2

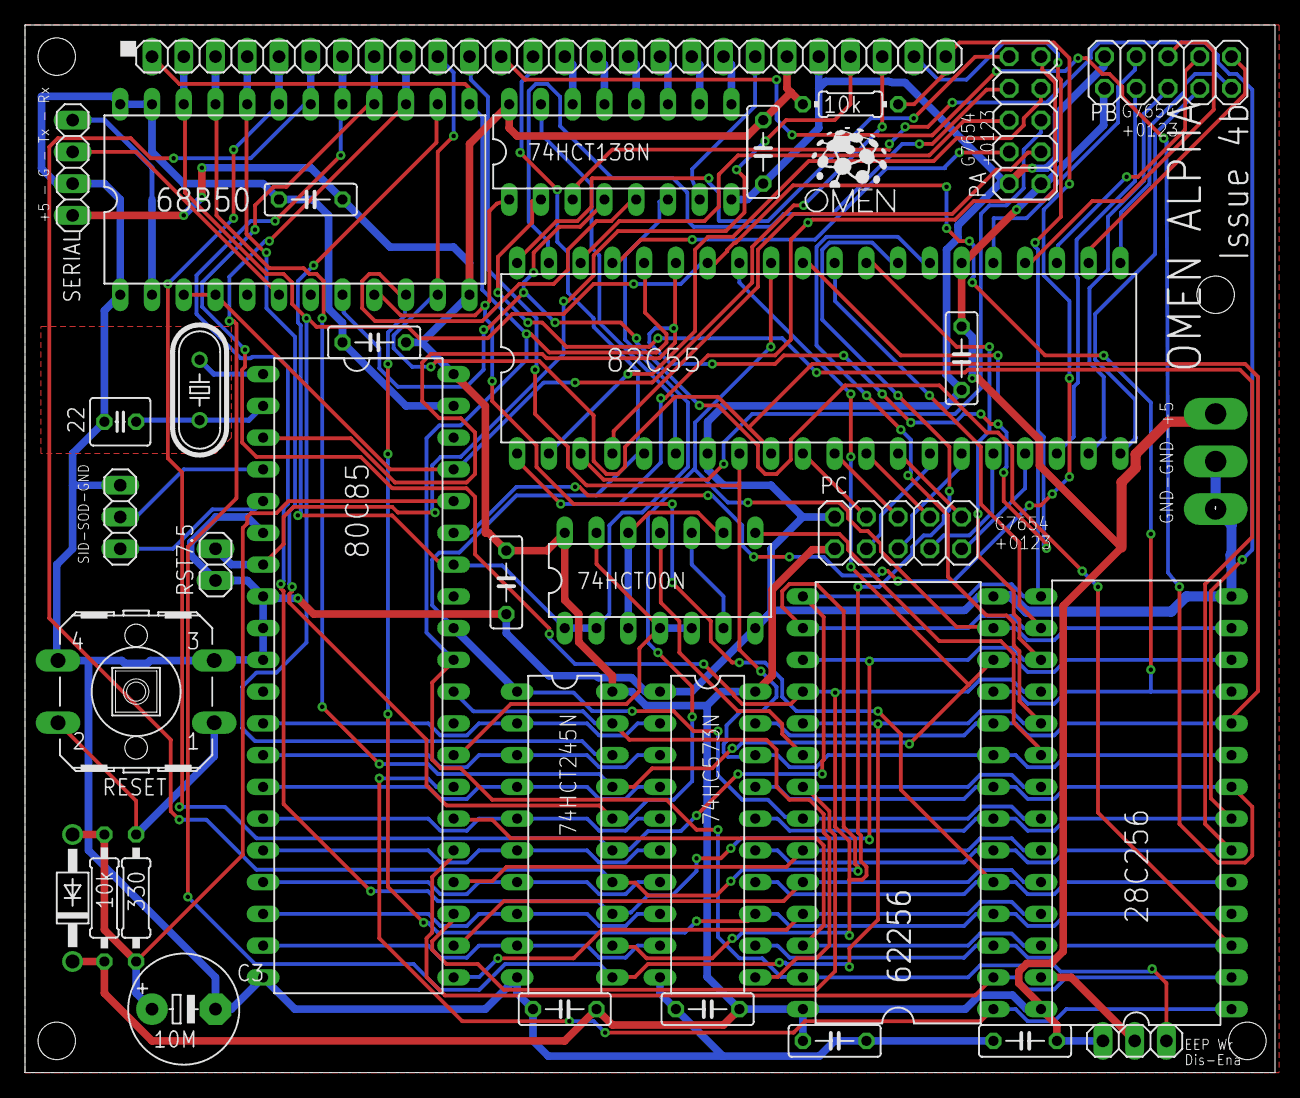
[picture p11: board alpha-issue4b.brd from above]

Board: 2 copper layers, 100.0 x 83.8 mm, 38 parts (0 on the bottom side), 87 nets.

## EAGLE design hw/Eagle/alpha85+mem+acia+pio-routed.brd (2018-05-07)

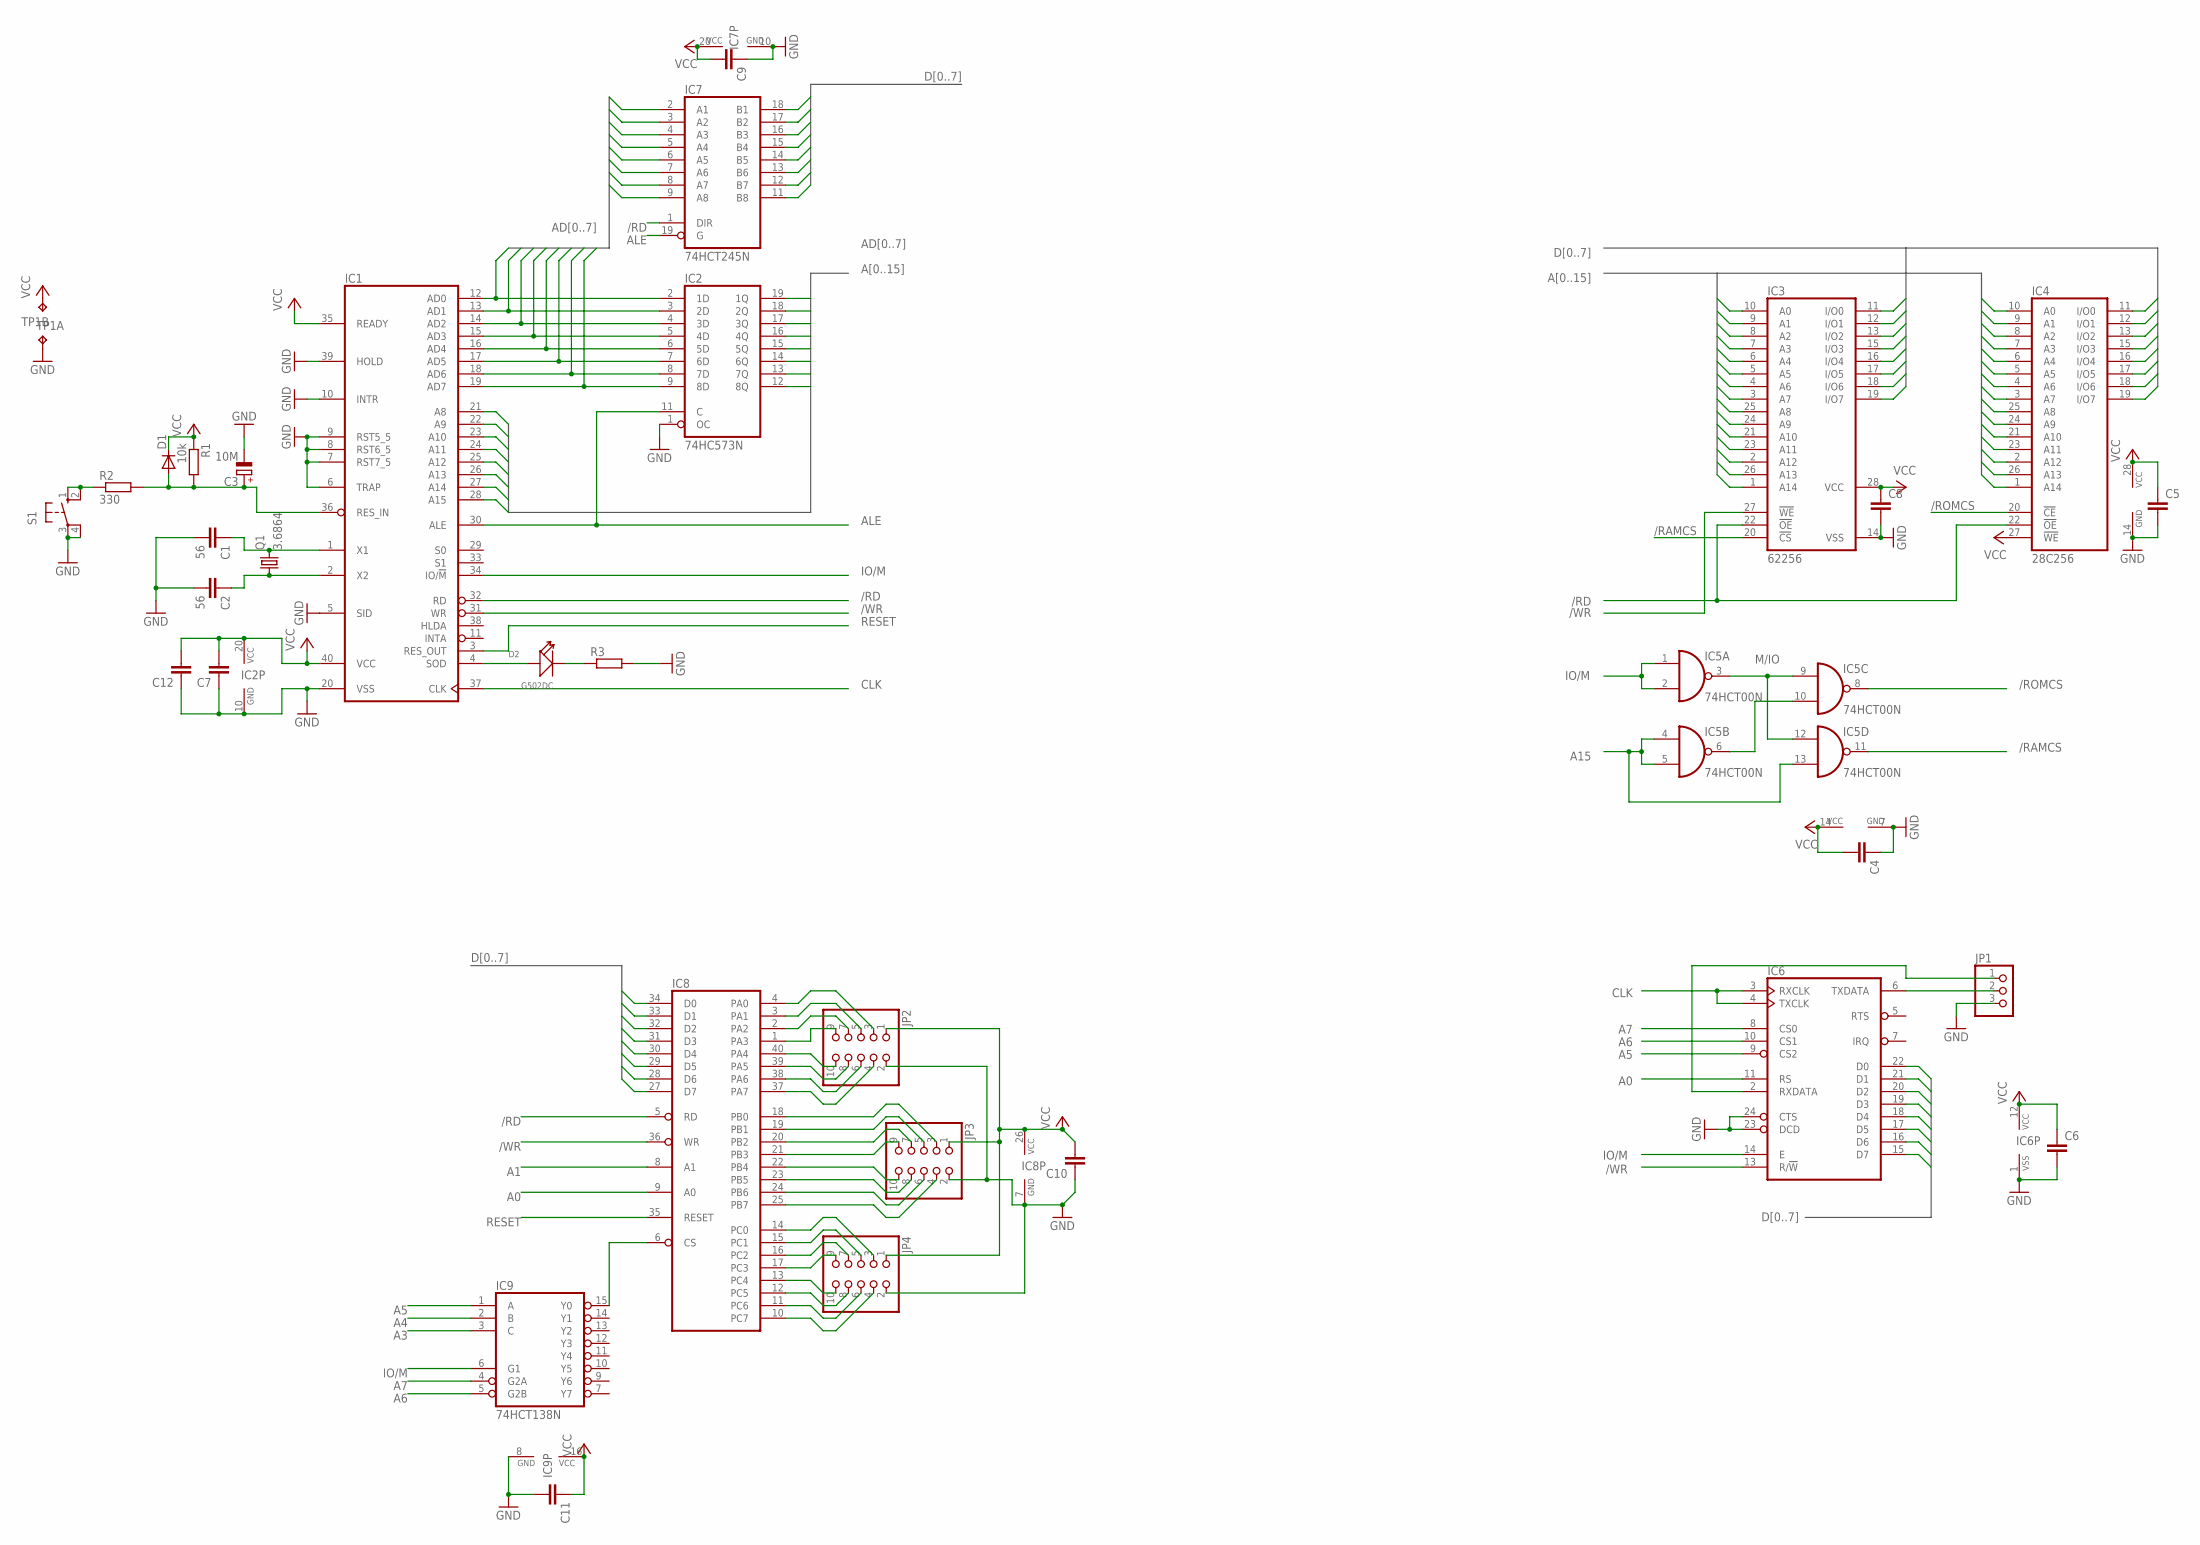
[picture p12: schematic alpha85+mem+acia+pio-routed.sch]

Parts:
C1, C2: 56; C025-040X050
C3: 10M; E5-8,5
C4, C5, C6, C7, C8, C9, C10, C11, C12: C-EU050-025X075; C050-025X075
D1: 1N4004; DO41-10
D2: G502DC; LED2-2.54-D5.0MM
IC1: 8085; DIL40
IC2: 74HC573N; DIL20
IC3: 62256; DIL28-6
IC4: 28C256; DIL28
IC5: 74HCT00N; DIL14
IC6: 6850; DIL24
IC7: 74HCT245N; DIL20
IC8: 8255A; DIL40
IC9: 74HCT138N; DIL16
JP1: PINHD-1X3; 1X03
JP2, JP3, JP4: PINHD-2X5; 2X05
Q1: 3.6864; HC49/S
R1: 10k; 0207/10
R2: 330; 0207/10
R3: R-EU_0207/7; 0207/7
S1: 40-XX; B3F-40XX
TP1: TP2P2-38-17; P2-38-17

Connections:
/RAMCS: IC3.20 (!CS), IC5.11 (O)
/RD: IC1.32 (RD), IC3.22 (!OE), IC4.22 (!OE), IC7.1 (DIR), IC8.5 (RD)
/ROMCS: IC4.20 (!CE), IC5.8 (O)
/WR: IC1.31 (WR), IC3.27 (!WE), IC6.13 (R/!W), IC8.36 (WR)
A0: IC2.19 (1Q), IC3.10 (A0), IC4.10 (A0), IC6.11 (RS), IC8.9 (A0)
A1: IC2.18 (2Q), IC3.9 (A1), IC4.9 (A1), IC8.8 (A1)
A2: IC2.17 (3Q), IC3.8 (A2), IC4.8 (A2)
A3: IC2.16 (4Q), IC3.7 (A3), IC4.7 (A3), IC9.3 (C)
A4: IC2.15 (5Q), IC3.6 (A4), IC4.6 (A4), IC9.2 (B)
A5: IC2.14 (6Q), IC3.5 (A5), IC4.5 (A5), IC6.9 (CS2), IC9.1 (A)
A6: IC2.13 (7Q), IC3.4 (A6), IC4.4 (A6), IC6.10 (CS1), IC9.5 (G2B)
A7: IC2.12 (8Q), IC3.3 (A7), IC4.3 (A7), IC6.8 (CS0), IC9.4 (G2A)
A8: IC1.21 (A8), IC3.25 (A8), IC4.25 (A8)
A9: IC1.22 (A9), IC3.24 (A9), IC4.24 (A9)
A10: IC1.23 (A10), IC3.21 (A10), IC4.21 (A10)
A11: IC1.24 (A11), IC3.23 (A11), IC4.23 (A11)
A12: IC1.25 (A12), IC3.2 (A12), IC4.2 (A12)
A13: IC1.26 (A13), IC3.26 (A13), IC4.26 (A13)
A14: IC1.27 (A14), IC3.1 (A14), IC4.1 (A14)
A15: IC1.28 (A15), IC5.4 (I0), IC5.5 (I1), IC5.13 (I1)
ALE: IC1.30 (ALE), IC2.11 (C), IC7.19 (G)
CLK: IC1.37 (CLK), IC6.3 (RXCLK), IC6.4 (TXCLK)
D0: IC3.11 (I/O0), IC4.11 (I/O0), IC6.22 (D0), IC7.18 (B1), IC8.34 (D0)
D1: IC3.12 (I/O1), IC4.12 (I/O1), IC6.21 (D1), IC7.17 (B2), IC8.33 (D1)
D2: IC3.13 (I/O2), IC4.13 (I/O2), IC6.20 (D2), IC7.16 (B3), IC8.32 (D2)
D3: IC3.15 (I/O3), IC4.15 (I/O3), IC6.19 (D3), IC7.15 (B4), IC8.31 (D3)
D4: IC3.16 (I/O4), IC4.16 (I/O4), IC6.18 (D4), IC7.14 (B5), IC8.30 (D4)
D5: IC3.17 (I/O5), IC4.17 (I/O5), IC6.17 (D5), IC7.13 (B6), IC8.29 (D5)
D6: IC3.18 (I/O6), IC4.18 (I/O6), IC6.16 (D6), IC7.12 (B7), IC8.28 (D6)
D7: IC3.19 (I/O7), IC4.19 (I/O7), IC6.15 (D7), IC7.11 (B8), IC8.27 (D7)
DX0: IC1.12 (AD0), IC2.2 (1D), IC7.2 (A1)
DX1: IC1.13 (AD1), IC2.3 (2D), IC7.3 (A2)
DX2: IC1.14 (AD2), IC2.4 (3D), IC7.4 (A3)
DX3: IC1.15 (AD3), IC2.5 (4D), IC7.5 (A4)
DX4: IC1.16 (AD4), IC2.6 (5D), IC7.6 (A5)
DX5: IC1.17 (AD5), IC2.7 (6D), IC7.7 (A6)
DX6: IC1.18 (AD6), IC2.8 (7D), IC7.8 (A7)
DX7: IC1.19 (AD7), IC2.9 (8D), IC7.9 (A8)
GND: C1.2, C2.2, C3.-, C4.1, C5.2, C6.2, C7.1, C8.2, C9.1, C10.1, C11.2, C12.1, IC1.5 (SID), IC1.6 (TRAP), IC1.7 (RST7_5), IC1.8 (RST6_5), IC1.9 (RST5_5), IC1.10 (INTR), IC1.20 (VSS), IC1.39 (HOLD), IC2.1 (OC), IC2.10 (GND), IC3.14 (VSS), IC4.14 (GND), IC5.7 (GND), IC6.1 (VSS), IC6.23 (DCD), IC6.24 (CTS), IC7.10 (GND), IC8.7 (GND), IC9.8 (GND), JP1.3, JP2.2, JP3.2, JP4.2, R3.2, S1.3, S1.4 (P1), TP1.TP-1
IO/M: IC1.34 (IO/!M), IC5.1 (I0), IC5.2 (I1), IC6.14 (E), IC9.6 (G1)
M/IO: IC5.3 (O), IC5.9 (I0), IC5.12 (I0)
unnamed: C1.1, IC1.1 (X1), Q1.2
unnamed: C2.1, IC1.2 (X2), Q1.1
unnamed: D2.+, IC1.4 (SOD)
unnamed: D2.-, R3.1
unnamed: IC6.6 (TXDATA), JP1.2
unnamed: C3.+, D1.A, IC1.36 (RES_IN), R1.2, R2.2
unnamed: R2.1, S1.1 (S), S1.2 (S1)
unnamed: IC5.6 (O), IC5.10 (I1)
unnamed: IC8.1 (PA3), JP2.9
unnamed: IC6.2 (RXDATA), JP1.1
unnamed: IC8.2 (PA2), JP2.7
unnamed: IC8.3 (PA1), JP2.5
unnamed: IC8.4 (PA0), JP2.3
unnamed: IC8.40 (PA4), JP2.10
unnamed: IC8.39 (PA5), JP2.8
unnamed: IC8.38 (PA6), JP2.6
unnamed: IC8.37 (PA7), JP2.4
unnamed: IC8.21 (PB3), JP3.9
unnamed: IC8.20 (PB2), JP3.7
unnamed: IC8.19 (PB1), JP3.5
unnamed: IC8.18 (PB0), JP3.3
unnamed: IC8.22 (PB4), JP3.10
unnamed: IC8.23 (PB5), JP3.8
unnamed: IC8.24 (PB6), JP3.6
unnamed: IC8.25 (PB7), JP3.4
unnamed: IC8.17 (PC3), JP4.9
unnamed: IC8.13 (PC4), JP4.10
unnamed: IC8.16 (PC2), JP4.7
unnamed: IC8.15 (PC1), JP4.5
unnamed: IC8.14 (PC0), JP4.3
unnamed: IC8.12 (PC5), JP4.8
unnamed: IC8.11 (PC6), JP4.6
unnamed: IC8.10 (PC7), JP4.4
unnamed: IC8.6 (CS), IC9.15 (Y0)
RESET: IC1.3 (RES_OUT), IC8.35 (RESET)
VCC: C4.2, C5.1, C6.1, C7.2, C8.1, C9.2, C10.2, C11.1, C12.2, D1.C, IC1.35 (READY), IC1.40 (VCC), IC2.20 (VCC), IC3.28 (VCC), IC4.27 (!WE), IC4.28 (VCC), IC5.14 (VCC), IC6.12 (VCC), IC7.20 (VCC), IC8.26 (VCC), IC9.16 (VCC), JP2.1, JP3.1, JP4.1, R1.1, TP1.TP-2

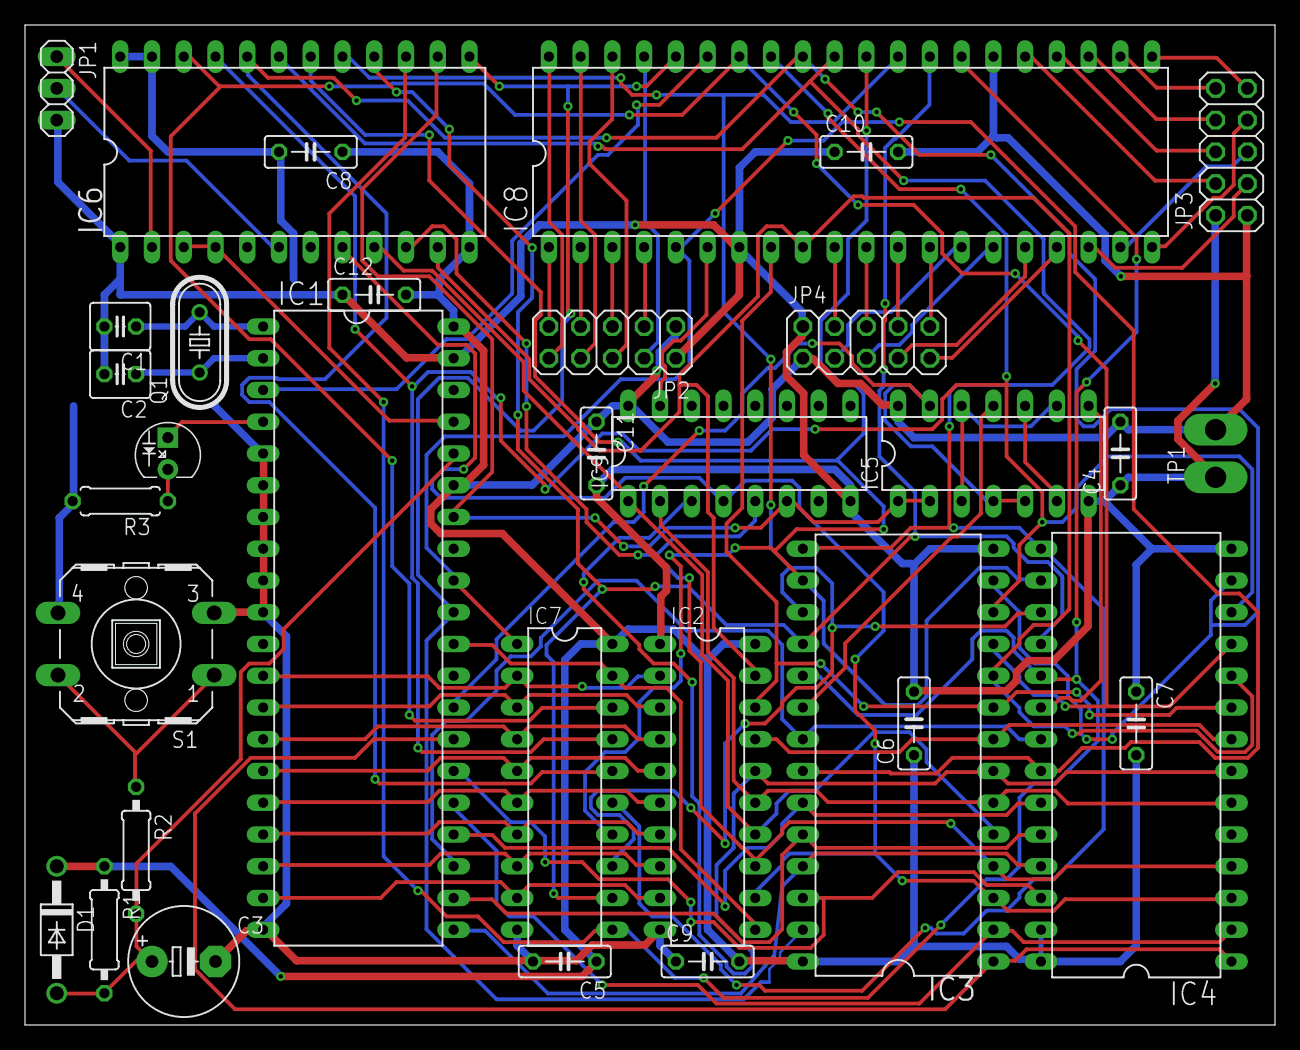
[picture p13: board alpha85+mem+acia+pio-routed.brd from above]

Board: 2 copper layers, 100.0 x 80.0 mm, 33 parts (0 on the bottom side), 77 nets.

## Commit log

2018-05-07 Schematic revised
    [alpha85+mem+acia+pio-routed.brd, alpha85+mem+acia+pio-routed.sch]
2018-06-17 issue 2 schematics,board
    [alpha-issue2-v23.brd, alpha-issue2-v23.sch]
2018-06-17 BRD REV
    [alpha-issue2-v23.brd, alpha-issue2-v23.sch]
2018-07-28 Assembly instructions
2018-08-12 Issue 4
    [alpha-issue4.brd, alpha-issue4.sch]
2019-05-17 Issue 4a
    Added:
    - holes
    - pin Vcc for serial port
    74138 moved away from 6850
    [alpha-issue4a.brd, alpha-issue4a.sch]
2019-05-25 issue 4b - new silk
    [alpha-issue4b.brd, alpha-issue4b.sch]
